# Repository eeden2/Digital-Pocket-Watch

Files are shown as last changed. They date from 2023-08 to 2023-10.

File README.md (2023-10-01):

# Digital-Pocket-Watch
This is my first invention which implements functionality for time, obviously, and a connection to a remote camera server.

# 3D-View
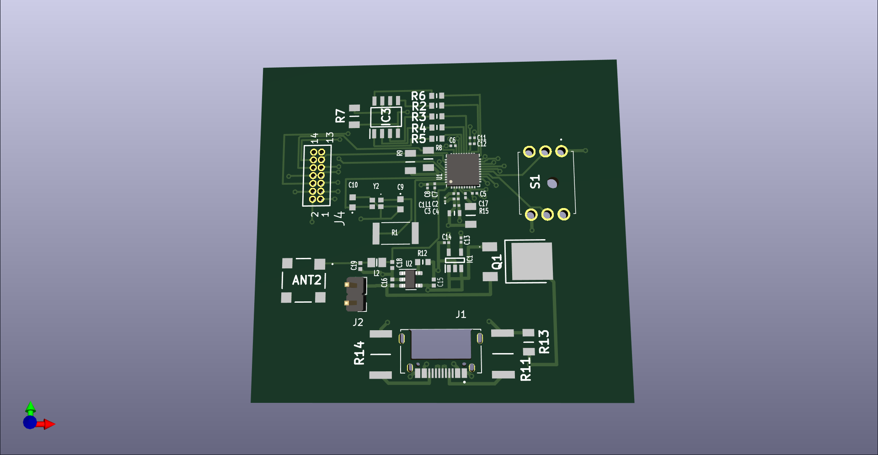
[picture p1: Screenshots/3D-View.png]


The parts are all in the mainv2/Footprints. A list here will be provided later.
- __UPDATE (10/01/2023)__
  
      The Firmware currently supports all fudamental rpotocols (I2C, WIFI, SPI, etc.)
      It also has the UI implemented for basic functionality,. Server setup for camera
      display is the only part left, but the lack of ability to manufacture it from costs
      could leave this project as is, finished.
- __The Drivers for the display are a GC9A01 SPI and a CST816S I2C Touch Interface__

# PCB
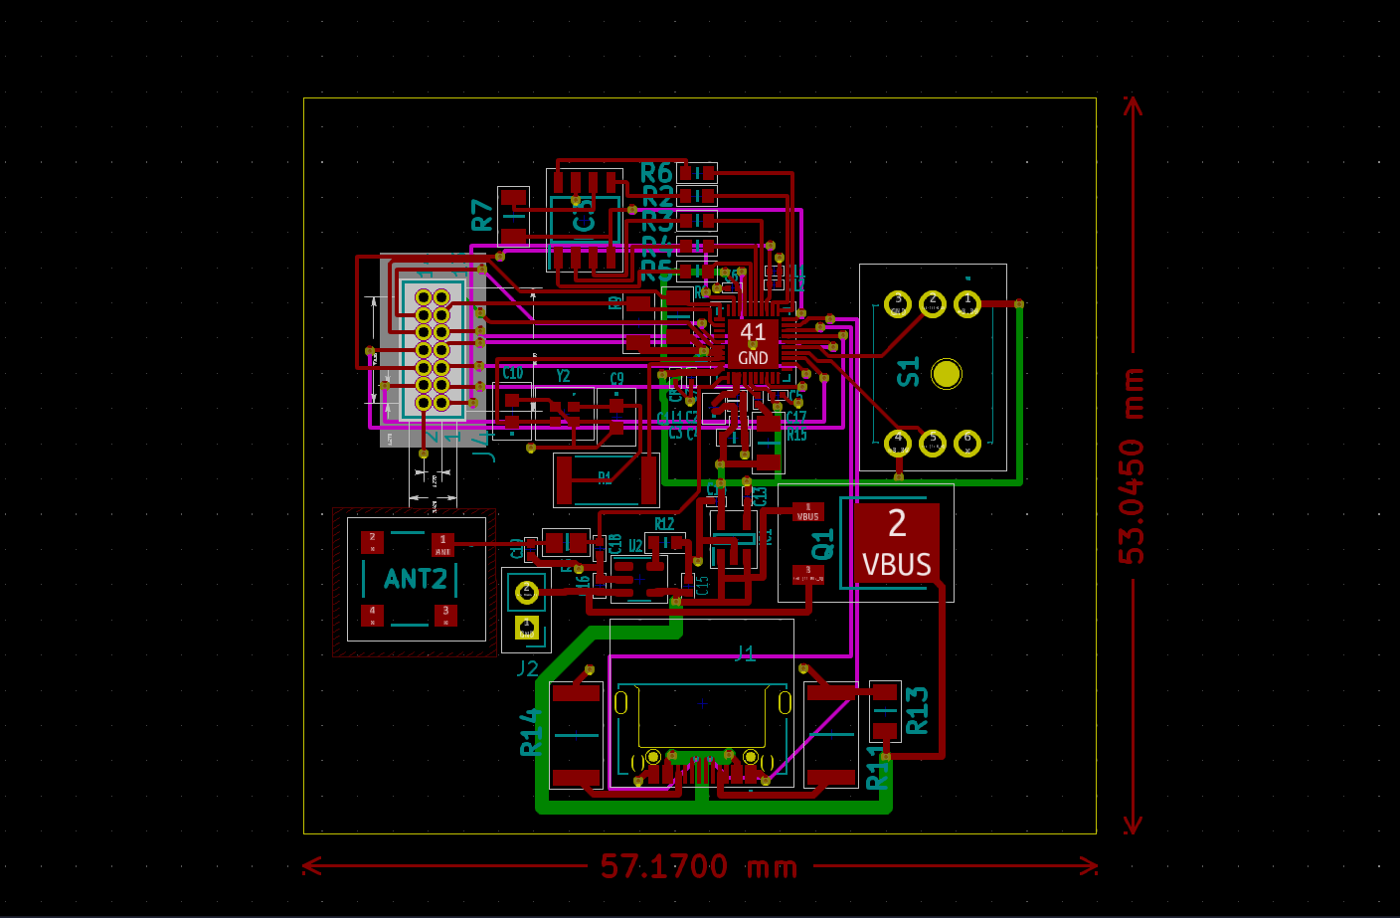
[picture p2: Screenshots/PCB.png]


# Schematic
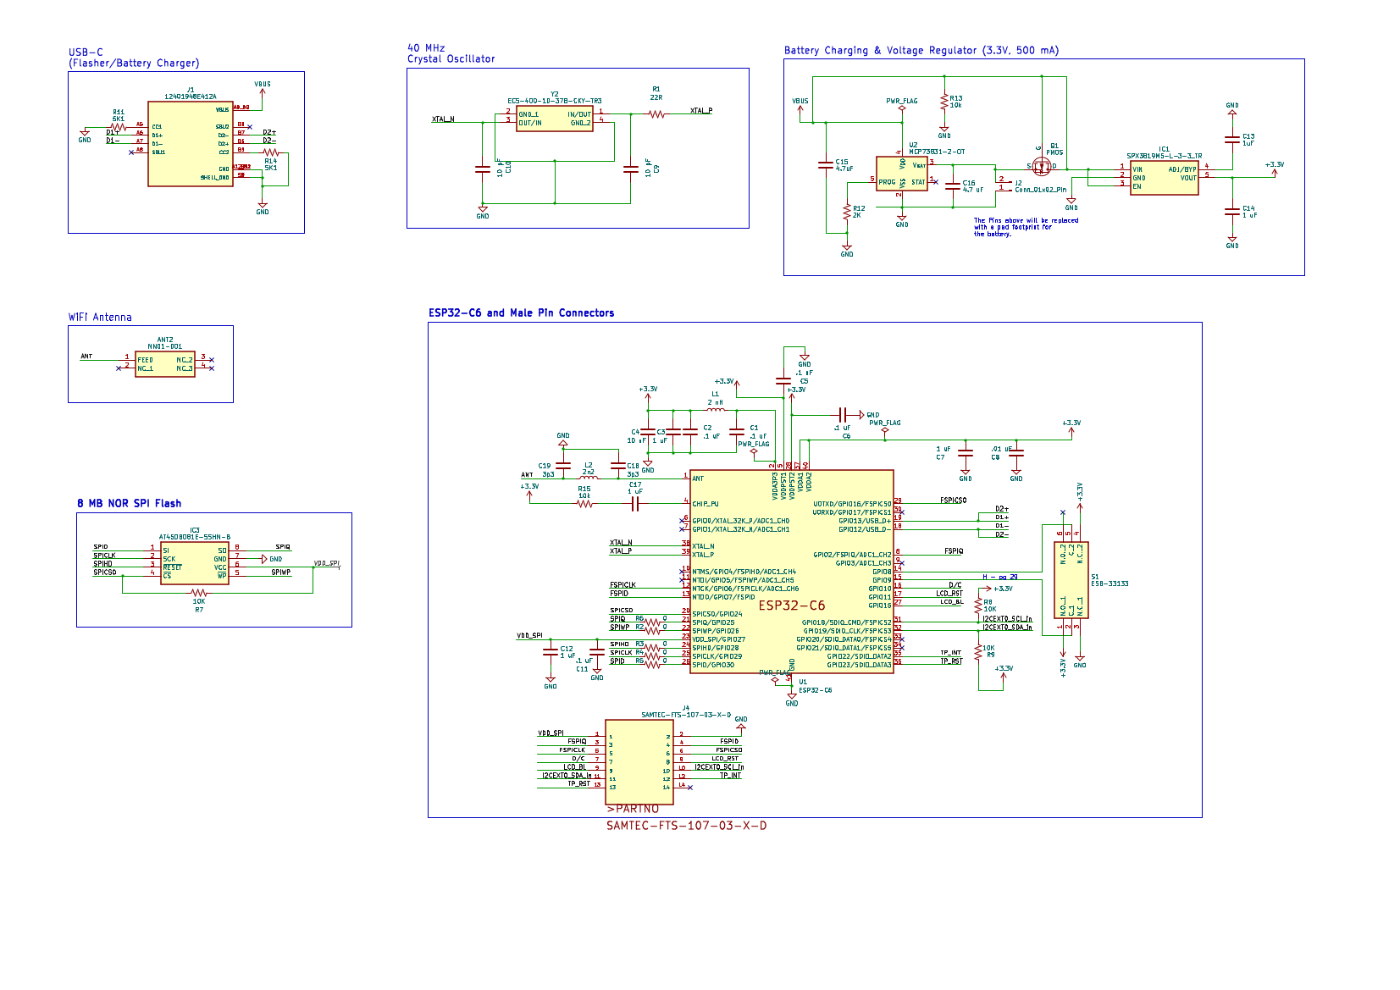
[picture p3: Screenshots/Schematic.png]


# UI Interface
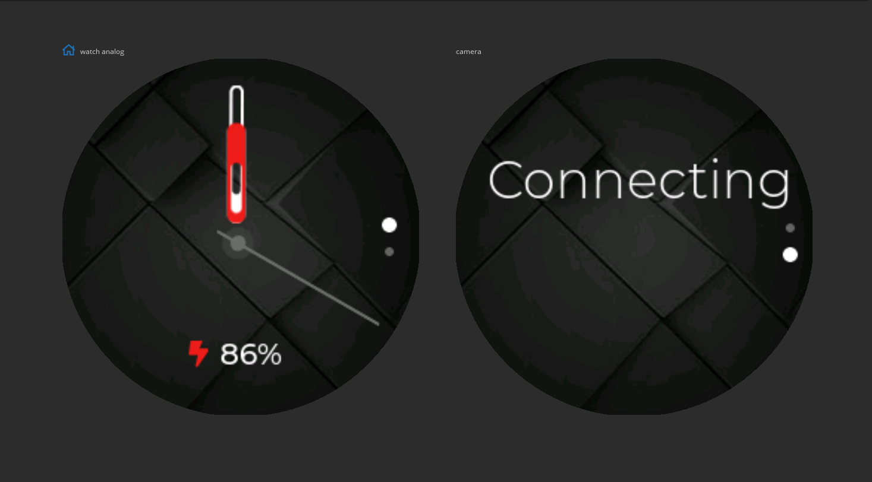
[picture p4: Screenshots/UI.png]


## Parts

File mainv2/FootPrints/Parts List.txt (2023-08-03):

Battery Charger (MCP73831T-5ACI/OT) - https://www.mouser.com/ProductDetail/Microchip-Technology/MCP73831T-5ACI-OT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
Flash (AT45DB081E-SSHN-T) - https://www.mouser.com/ProductDetail/Renesas-Dialog/AT45DB081E-SSHN-T?qs=IS%252B4QmGtzzrT9yP%2Fj4syVA%3D%3D
Battery - https://www.alibaba.com/product-detail/553535-3-7V-battery-580mah-round_60692201528.html
Button Switch (ESB-33133) - https://www.mouser.com/ProductDetail/Panasonic/ESB-33133?qs=9gtMhpKs0nEQdT3ey0aRGQ%3D%3D
Antenna (NN01-001)- https://www.mouser.com/ProductDetail/Ignion/NN01-001?qs=bAKSY%2FctAC4amJyoGr5q7A%3D%3D
Regulator (SPX3819M5-L-3-3/TR) - https://www.mouser.com/ProductDetail/MaxLinear/SPX3819M5-L-3-3-TR?qs=S%2FCBhQS5rCp1Bb7a%252BD%2FCBQ%3D%3D
Crystal (ECS-400-10-37B-CKY-TR3) - https://www.mouser.com/ProductDetail/ECS/ECS-400-10-37B-CKY-TR3?qs=TCDPyi3sCW2VtaBG%252B2IQWA%3D%3D
USB-C (12402012E212A) - https://www.mouser.com/ProductDetail/Amphenol-Commercial-Products/12402012E212A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
Display - https://www.waveshare.com/1.28inch-Touch-LCD.htm
PMOSFET - https://www.mouser.com/ProductDetail/Vishay-Semiconductors/IRFR9210PBF-BE3?qs=TCDPyi3sCW1nNZLR7LYV3w%3D%3D
13 Pin - https://www.snapeda.com/parts/TSM-113-02-T-SV-A-P-TR/Samtec/view-part/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
0 Ohm - https://www.mouser.com/ProductDetail/Ohmite/JR2512X100E?qs=sGAEpiMZZMtlubZbdhIBIM7uh3w%252BIHxmov0Yd5cNh5Y%3D
22 Ohm - https://www.snapeda.com/parts/CRGP2512F22R/TE%20Connectivity/view-part/?ref=search&t=CRGP2512F22R
10k Ohm - https://www.mouser.com/ProductDetail/Bourns/CRM2512QJW-103ELF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
2k Ohm - https://www.mouser.com/ProductDetail/TE-Connectivity-Holsworthy/35212K0FT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
5.1K OHms - https://www.mouser.com/ProductDetail/TE-Connectivity-Holsworthy/35215K1FT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
1 uF - https://www.mouser.com/ProductDetail/KEMET/C1206F105M5RACAUTO7210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
10 nF - https://www.mouser.com/ProductDetail/KYOCERA-AVX/02014D103KAT2A?qs=cnDM9bjyeUgAPyHqQrA07A%3D%3D
2.2nH - https://www.mouser.com/ProductDetail/Bourns/CE201210-2N2D?qs=8tpky8Qe03K8mDIr14buog%3D%3D
3.3 pF - https://www.mouser.com/ProductDetail/Murata-Electronics/GJM1555C1H3R3WB01D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

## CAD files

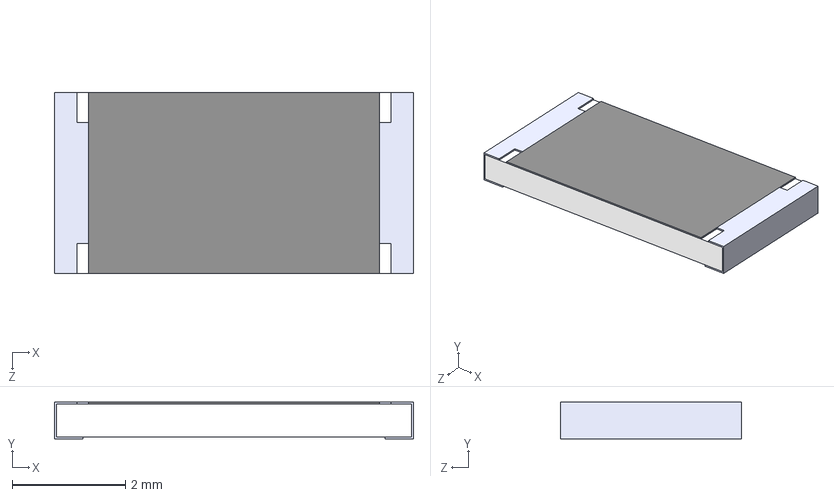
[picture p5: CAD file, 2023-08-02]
mainv2/FootPrints/CRGP2512F22R - 22Ohm/CRGP2512F22R.step
6.35 x 0.65 x 3.20 mm

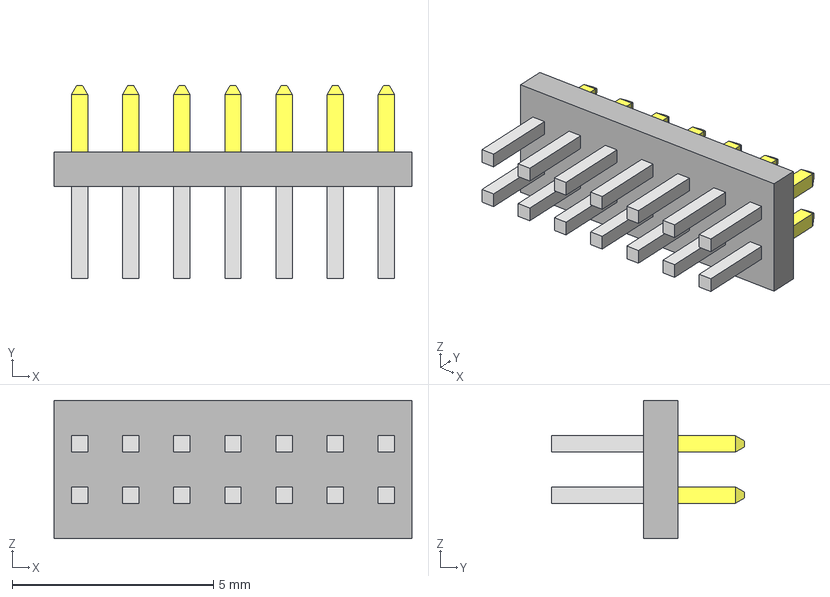
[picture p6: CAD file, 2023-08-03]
mainv2/FootPrints/FTS-107-03-L-D - 14 Pins/FTS-107-03-L-D.stp
8.89 x 4.80 x 3.43 mm
FTS-107-03-L-D_pins2
FTS-107-03-L-D_pins1
FTS-107-03-L-D_body

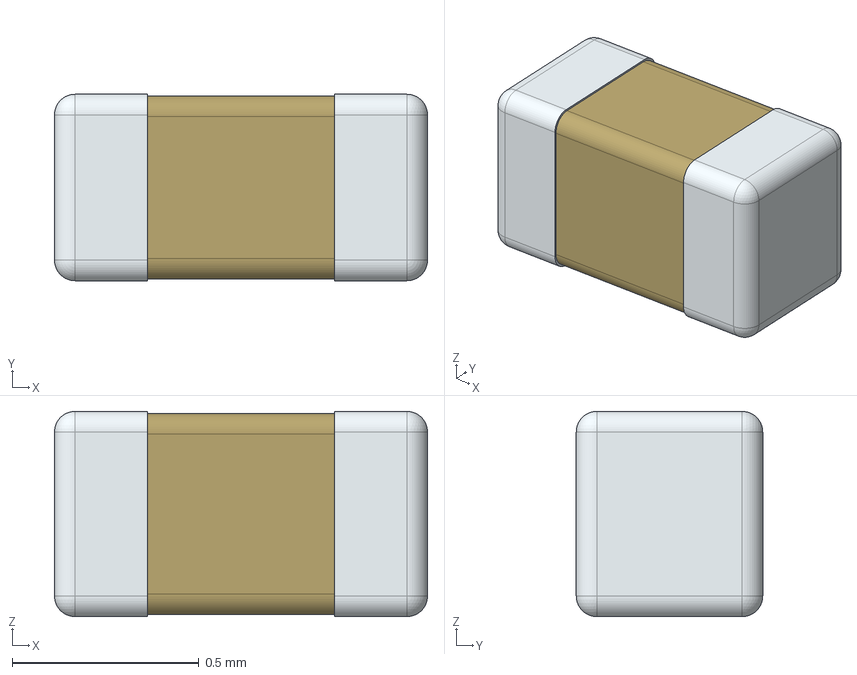
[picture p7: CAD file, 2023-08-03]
mainv2/FootPrints/LIB_GJM1555C1H3R3WB01D - 3.3pF/GJM1555C1H3R3WB01D/3D/GJM1555C1H3R3WB01D.stp
1.00 x 0.5 x 0.55 mm

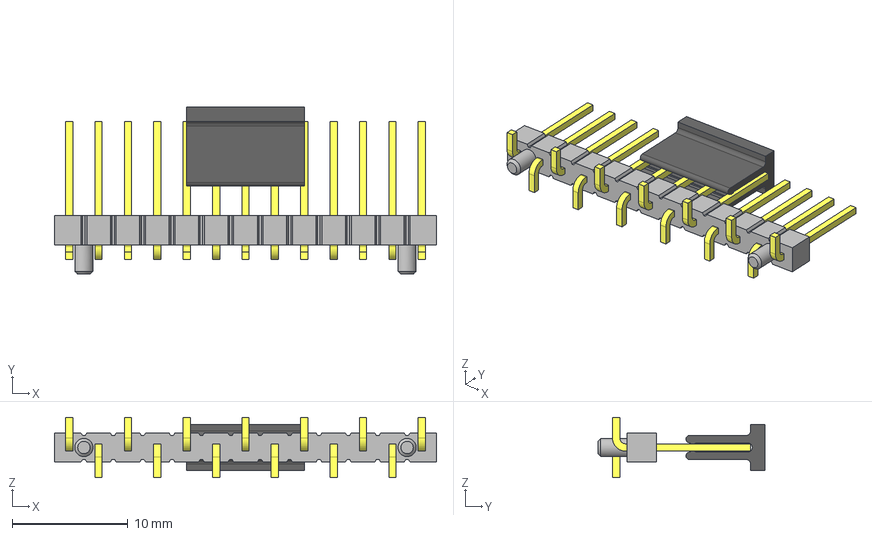
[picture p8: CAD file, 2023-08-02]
mainv2/FootPrints/TSM-113-02-T-SV-A - 13 PINS/TSM-113-02-T-SV-A.step
33.0 x 14.5 x 5.21 mm
T-1S6-08(-02-13-SV)
PPP-07-02-13--SV
TSM-113-02-SV-A_body

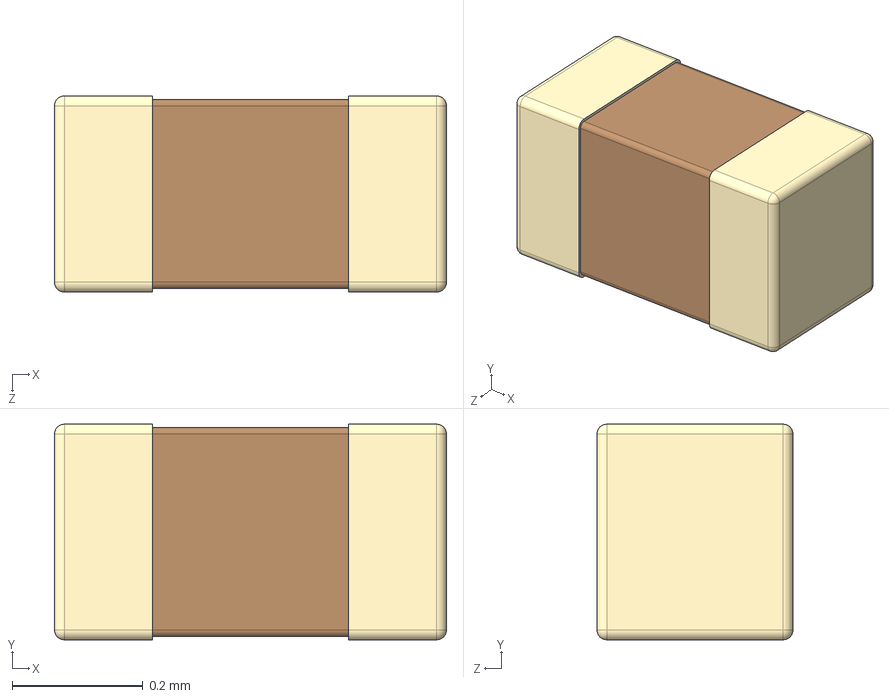
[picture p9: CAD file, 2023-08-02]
mainv2/FootPrints/02014D103KAT2A - 10 nF/02014D103KAT2A.step
0.6 x 0.33 x 0.3 mm

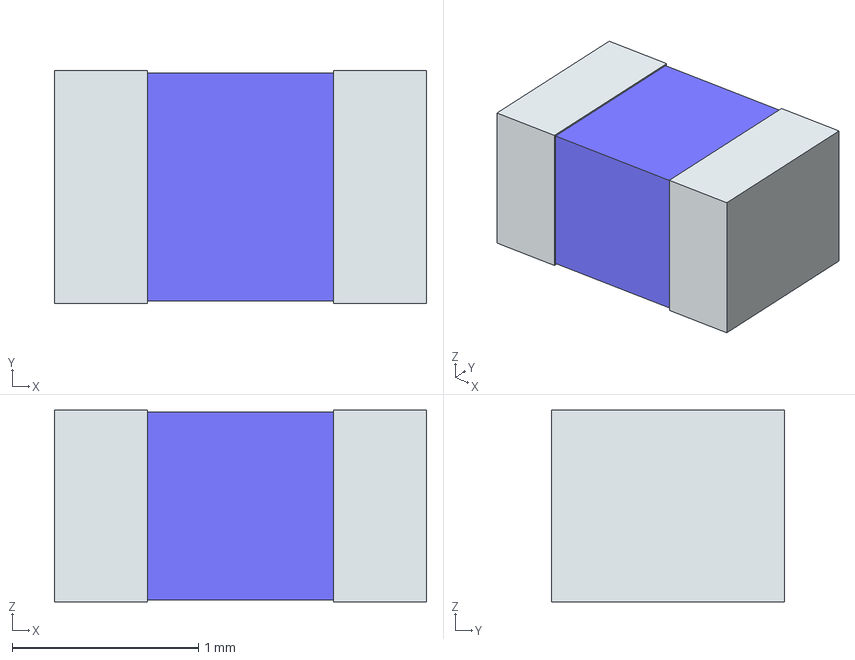
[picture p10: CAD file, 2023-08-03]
mainv2/FootPrints/LIB_CE201210-2N2D - 2.2 nH/CE201210-2N2D/3D/CE201210-2N2D.stp
2.00 x 1.25 x 1.03 mm
term1
term2

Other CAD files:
mainv2/FootPrints/LIB_CE201210-2N2D - 2.2 nH/CE201210-2N2D/Allegro/indc2012x103n.psm
mainv2/FootPrints/LIB_CE201210-2N2D - 2.2 nH/CE201210-2N2D/DEHDL/ce201210_2n2d/chips/chips.prt
mainv2/FootPrints/LIB_GJM1555C1H3R3WB01D - 3.3pF/GJM1555C1H3R3WB01D/Allegro/capc1005x55n.psm
mainv2/FootPrints/LIB_GJM1555C1H3R3WB01D - 3.3pF/GJM1555C1H3R3WB01D/DEHDL/gjm1555c1h3r3wb01d/chips/chips.prt

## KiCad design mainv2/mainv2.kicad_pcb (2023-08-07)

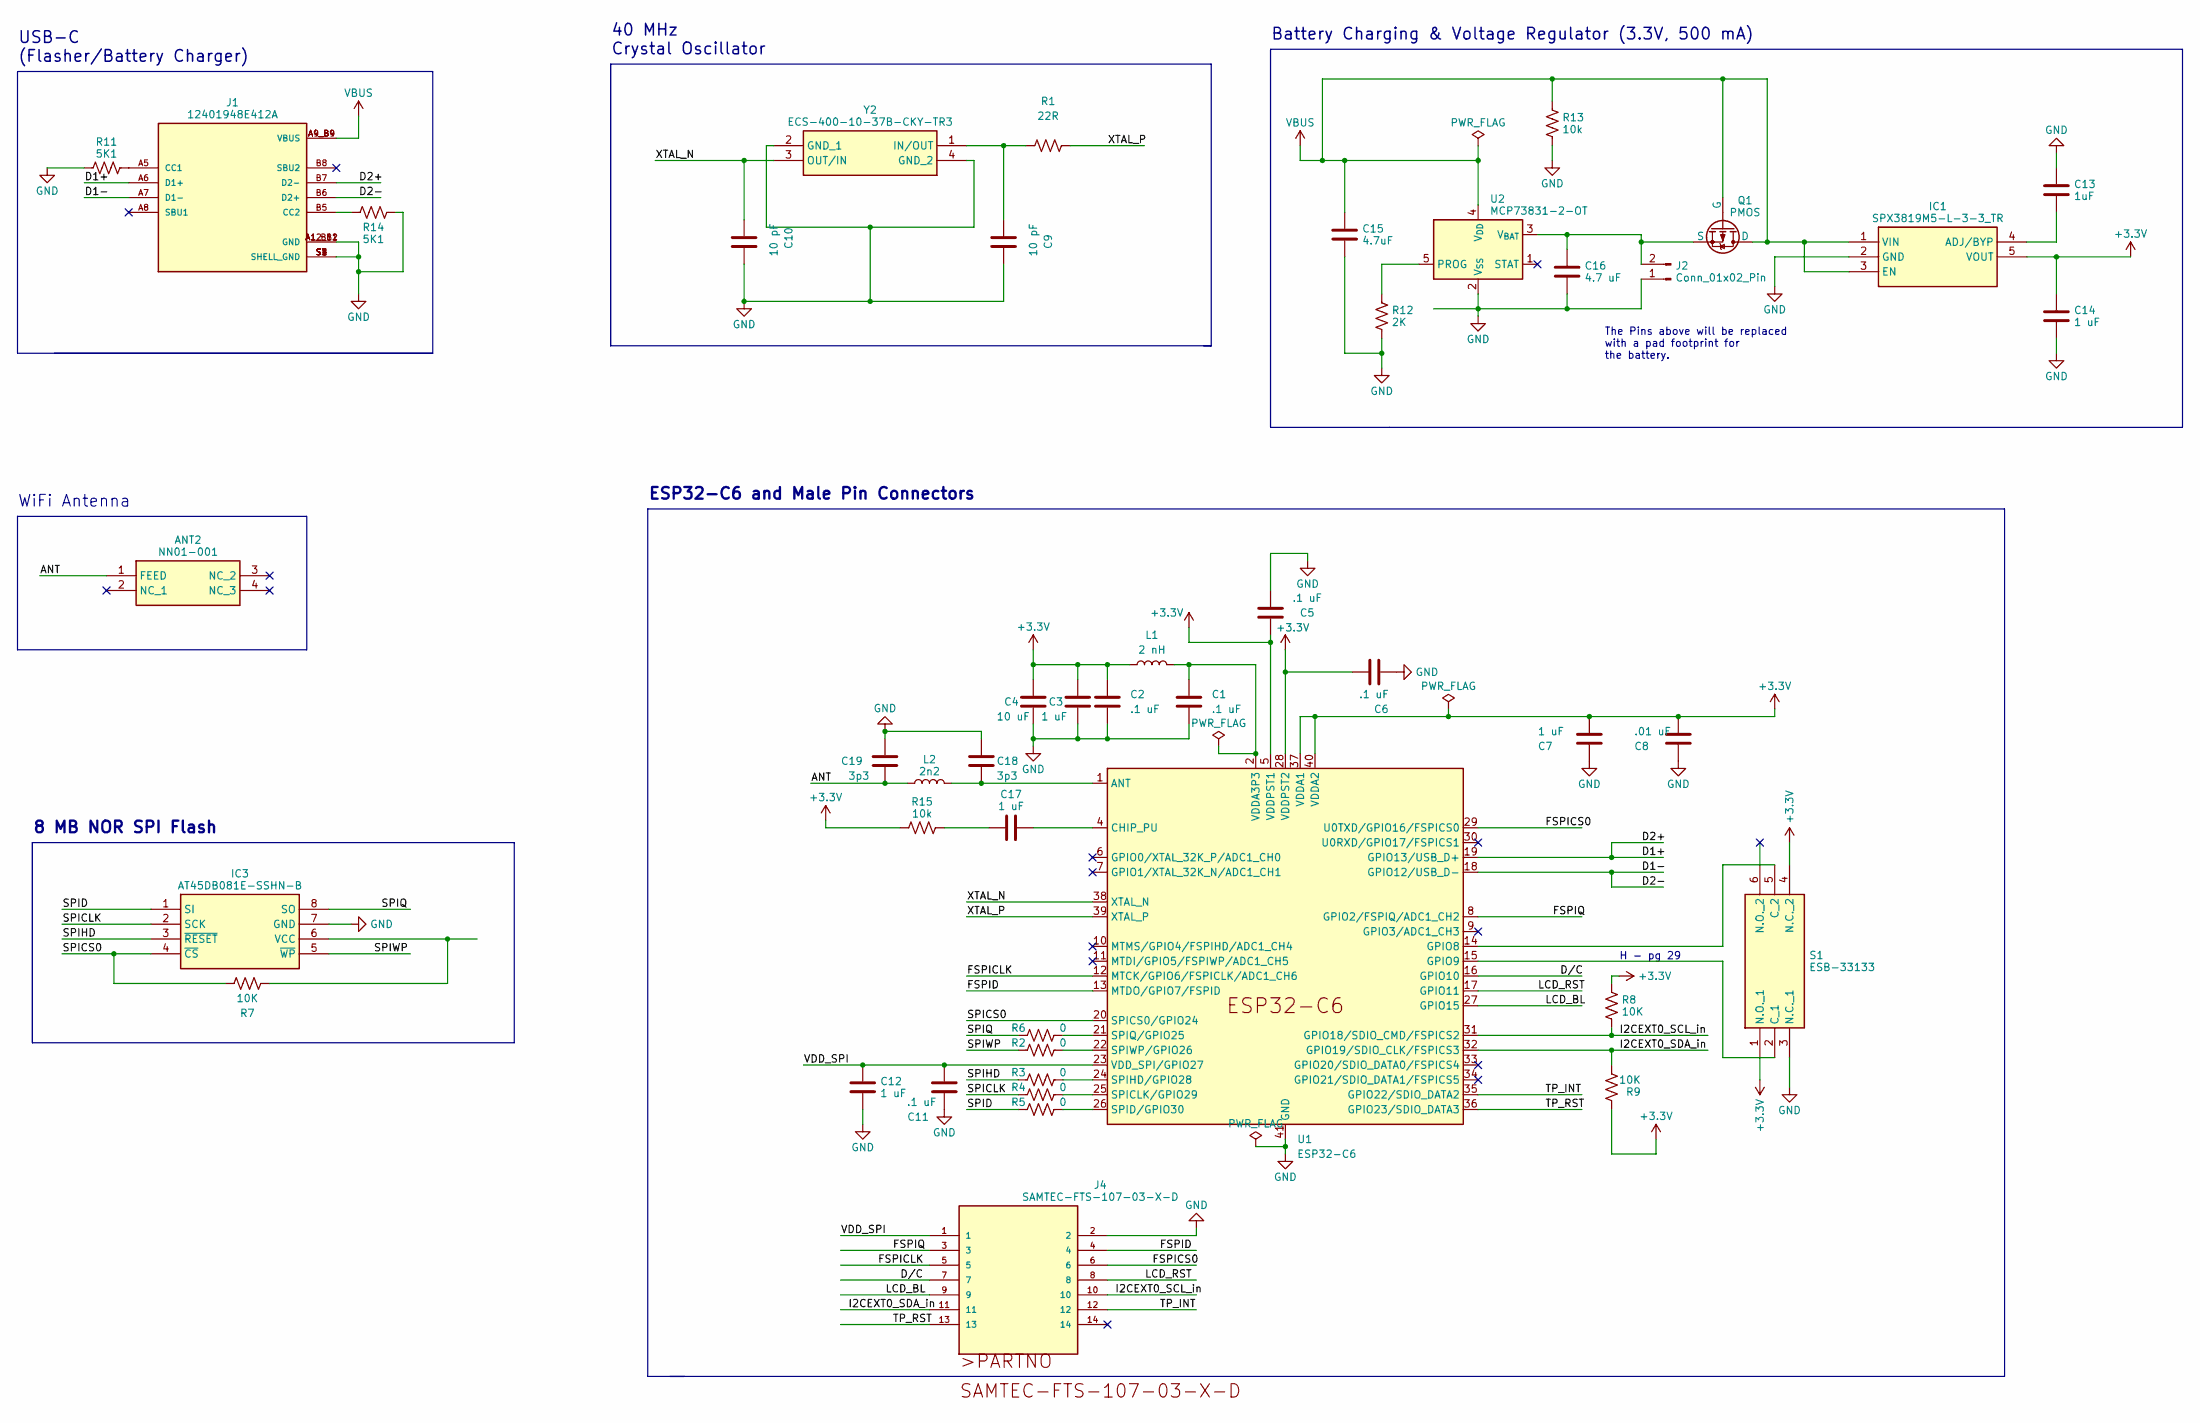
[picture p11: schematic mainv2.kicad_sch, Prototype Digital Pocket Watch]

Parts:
ANT2: NN01-001; NN01001; Manufacturer_Part_Number NN01-001
C1, C2, C5, C6, C11: .1 uF; CAPC0603X33N
C3, C7, C12, C14, C17: 1 uF; CAPC0603X35N
C4: 10 uF; CAPC1608X90N
C8: .01 uF; CAPC0603X33N
C9, C10: 10 pF; C0603
C13: 1uF; CAPC0603X35N
C15: 4.7uF; CAPC1005X55N
C16: 4.7 uF; CAPC1005X55N
C18, C19: 3p3; CAPC1005X55N
IC1: SPX3819M5-L-3-3_TR; SOT95P280X145-5N; Mouser Part Number 701-SPX3819M5-L-33TR
IC3: AT45DB081E-SSHN-B; SOIC127P600X175-8N; Mouser Part Number 988-AT45DB081ESSHN-B
J1: 12401948E412A; AMPHENOL_12401948E412A; PARTREV 3
J2: Conn_01x02_Pin; PinHeader_1x02_P2.54mm_Vertical
J4: SAMTEC-FTS-107-03-X-D
L1: 2 nH; MLG0603
L2: 2n2; INDC2012X103N
Q1: PMOS; IRFR9210PBFBE3
R1: 22R; RESC6332X65N
R2, R3, R4, R5, R6: 0; RESC1608X55N
R7, R8, R9: 10K; RESC3116X65N
R11, R14: 5K1; RESC6432X65N
R12: 2K; RESC1608X55N
R13, R15: 10k; RESC3116X65N
S1: ESB-33133; ESB33133; Mouser Part Number 667-ESB-33133
U1: ESP32-C6; QFN-40-1EP_5x5mm_P0.4mm_EP3.6x3.6mm
U2: MCP73831-2-OT; SOT-23-5
Y2: ECS-400-10-37B-CKY-TR3; ECS4001037BCKYTR3; Mouser Part Number 520-EC4001037BCKYTR3

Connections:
+3.3V: C2.1, C3.1, C4.1, C5.1, C6.1, C7.1, C8.1, C14.1, IC1.5 (VOUT), L1.1, R8.1, R9.1, R15.1, S1.1 (N.O._1), S1.4 (N.C._2), U1.5 (VDDPST1), U1.28 (VDDPST2), U1.37 (VDDA1), U1.40 (VDDA2)
/ANT: ANT2.1 (FEED), C19.2, L2.1
/D1+: J1.A6 (D1+), J1.B7 (D2-), U1.19 (GPIO13/USB_D+)
/D1-: J1.A7 (D1-), J1.B6 (D2+), U1.18 (GPIO12/USB_D-)
/D/C: J4.7, U1.16 (GPIO10)
/FSPICLK: J4.5, U1.12 (MTCK/GPIO6/FSPICLK/ADC1_CH6)
/FSPICS0: J4.6, U1.29 (U0TXD/GPIO16/FSPICS0)
/FSPID: J4.4, U1.13 (MTDO/GPIO7/FSPID)
/FSPIQ: J4.3, U1.8 (GPIO2/FSPIQ/ADC1_CH2)
/I2CEXT0_SCL_in: J4.10, R8.2, U1.31 (GPIO18/SDIO_CMD/FSPICS2)
/I2CEXT0_SDA_in: J4.11, R9.2, U1.32 (GPIO19/SDIO_CLK/FSPICS3)
/LCD_BL: J4.9, U1.27 (GPIO15)
/LCD_RST: J4.8, U1.17 (GPIO11)
/SPICLK: IC3.2 (SCK), R4.1
/SPICS0: IC3.4 (~CS), R7.1, U1.20 (SPICS0/GPIO24)
/SPID: IC3.1 (SI), R5.1
/SPIHD: IC3.3 (~RESET), R3.1
/SPIQ: IC3.8 (SO), R6.1
/SPIWP: IC3.5 (~WP), R2.1
/TP_INT: J4.12, U1.35 (GPIO22/SDIO_DATA2)
/TP_RST: J4.13, U1.36 (GPIO23/SDIO_DATA3)
/VDD_SPI: C11.2, C12.2, J4.1, U1.23 (VDD_SPI/GPIO27)
/XTAL_N: C10.1, U1.38 (XTAL_N), Y2.3 (OUT/IN)
/XTAL_P: R1.2, U1.39 (XTAL_P)
GND: C1.2, C2.2, C3.2, C4.2, C5.2, C6.2, C7.2, C8.2, C9.2, C10.2, C11.1, C12.1, C13.1, C14.2, C15.2, C16.2, C18.1, C19.1, IC1.2 (GND), IC3.7 (GND), J1.A1_B12 (GND), J1.A12_B1 (GND), J1.S1 (SHELL_GND), J1.S2 (SHELL_GND), J1.S3 (SHELL_GND), J1.S4 (SHELL_GND), J2.1, J4.2, R11.1, R12.2, R13.2, R14.2, S1.3 (N.C._1), U1.41 (GND), U2.2 (V_{SS}), Y2.2 (GND_1), Y2.4 (GND_2)
unnamed: C1.1, L1.2, U1.2 (VDDA3P3), U1.3 (VDDA3P3)
unnamed: C17.1, R15.2
unnamed: C13.2, IC1.4 (ADJ/BYP)
unnamed: IC3.6 (VCC), R7.2
unnamed: J1.A5 (CC1), R11.2
unnamed: J1.B5 (CC2), R14.1
unnamed: C16.1, J2.2, Q1.3 (S), U2.3 (V_{BAT})
unnamed: S1.2 (C_1), U1.15 (GPIO9)
unnamed: S1.5 (C_2), U1.14 (GPIO8)
unnamed: C18.2, L2.2, U1.1 (ANT)
unnamed: C17.2, U1.4 (CHIP_PU)
unnamed: R4.2, U1.25 (SPICLK/GPIO29)
unnamed: R5.2, U1.26 (SPID/GPIO30)
unnamed: R3.2, U1.24 (SPIHD/GPIO28)
unnamed: R6.2, U1.21 (SPIQ/GPIO25)
unnamed: R2.2, U1.22 (SPIWP/GPIO26)
unnamed: R12.1, U2.5 (PROG)
unnamed: C9.1, R1.1, Y2.1 (IN/OUT)
VBUS: C15.1, IC1.1 (VIN), IC1.3 (EN), J1.A4_B9 (VBUS), J1.A9_B4 (VBUS), Q1.1 (D), Q1.2 (G), R13.1, U2.4 (V_{DD})

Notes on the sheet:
H - pg 29
ESP32-C6 and Male Pin Connectors
The Pins above will be replaced with a pad footprint for the battery.
USB-C (Flasher/Battery Charger)
Battery Charging & Voltage Regulator (3.3V, 500 mA)
WiFi Antenna
8 MB NOR SPI Flash
40 MHz Crystal Oscillator

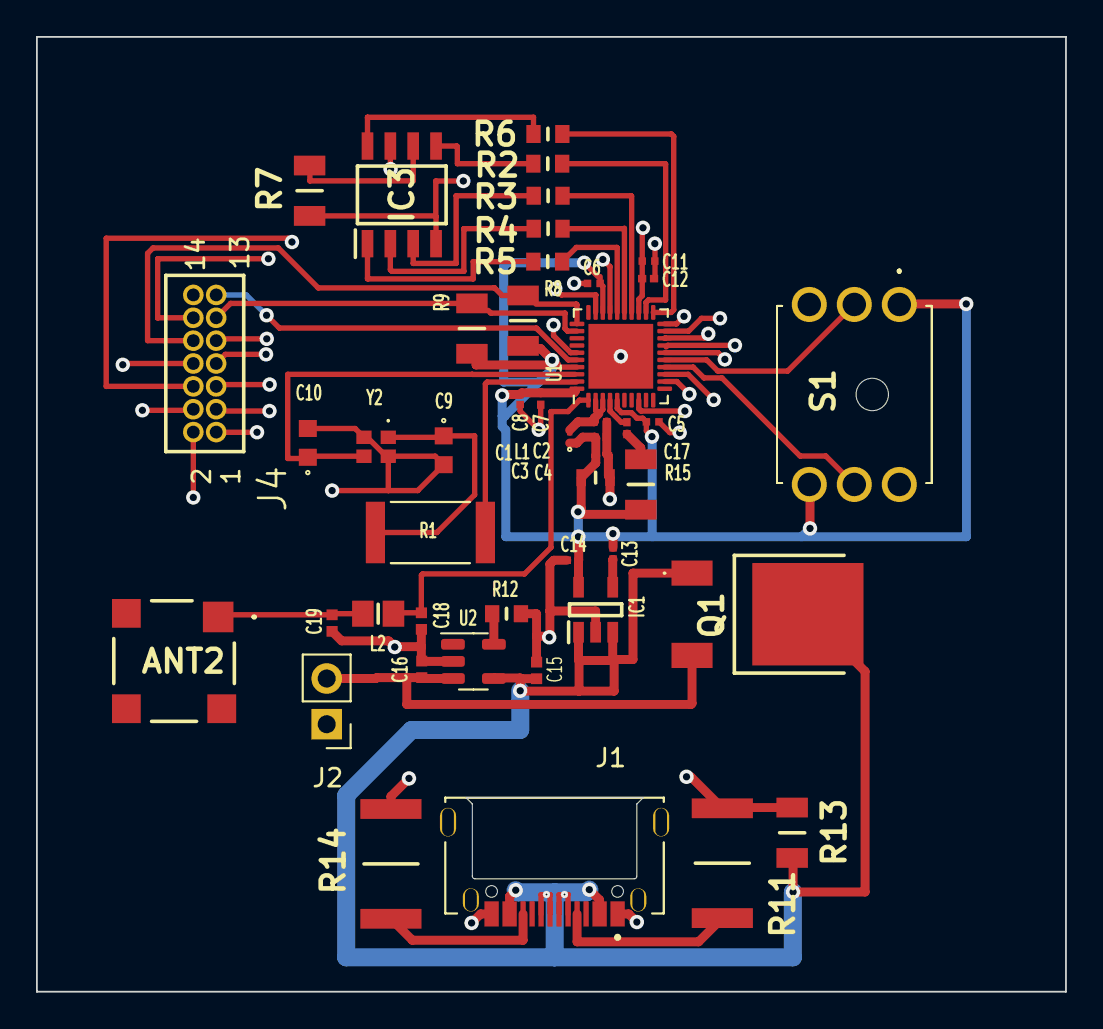
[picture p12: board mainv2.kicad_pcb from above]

Board: 4 copper layers, 57.2 x 53.0 mm, 46 parts (0 on the bottom side), 44 nets.

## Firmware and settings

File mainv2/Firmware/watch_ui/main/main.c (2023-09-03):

#include <stdio.h>
#include <lvgl.h>
#include <inttypes.h>
#include "sdkconfig.h"
#include "freertos/FreeRTOS.h"
#include "freertos/task.h"
#include <esp_timer.h>
#include "driver/gpio.h"
#include "esp_log.h"
#include "esp_err.h"
#include "hal/lcd_types.h"
#include "gpio.h"
#include "esp_lcd_panel_io.h"
#include "esp_lcd_gc9a01.h"
#include "esp_lcd_panel_vendor.h"
#include "esp_lcd_panel_ops.h"
#include "protocols/I2C.c"
#include "protocols/SPI.c"
#include "protocols/WIFI.c"
#include "signal.h"
#include "spi_master.h"
#include "ui/ui.c"
#include "protocols/timer_replacement.h" // This file was made due to the esp_timer.h not allowing use of its defined functions.

#define FSPIQ_IN_IDX                  64
#define FSPIQ_OUT_IDX                 64
#define FSPID_IN_IDX                  65
#define FSPID_OUT_IDX                 65
#define FSPICS0_IN_IDX                68
#define FSPICS0_OUT_IDX               68
#define LCD_HOST SPI2_HOST

#define portTICK_PERIOD_MS      1                       //This was defined manually because my IDE was not reading it from "sdkconfig.h"

#define LVGL_TICK_PERIOD_MS     2

//Antenna
#define ANT                     1

//USB Diffs
#define D_PLUS                  GPIO_NUM_13
#define D_NEG                   GPIO_NUM_12

//Flash Switch for when Chip is in download mode or regular SPI mode
#define FIRST_SWITCH            GPIO_NUM_8
#define SECOND_SWITCH           GPIO_NUM_9


extern void lvgl_demo_ui(lv_disp_t *disp);


static bool notify_lvgl_flush_ready(esp_lcd_panel_io_handle_t panel_io, esp_lcd_panel_io_event_data_t *edata, void *user_ctx)
{
    lv_disp_drv_t *disp_driver = (lv_disp_drv_t *)user_ctx;
    lv_disp_flush_ready(disp_driver);
    return false;
}

static void lvgl_flush_cb(lv_disp_drv_t *drv, const lv_area_t *area, lv_color_t *color_map)
{
    esp_lcd_panel_handle_t panel_handle = (esp_lcd_panel_handle_t) drv->user_data;
    int offsetx1 = area->x1;
    int offsetx2 = area->x2;
    int offsety1 = area->y1;
    int offsety2 = area->y2;
    // copy a buffer's content to a specific area of the display
    esp_lcd_panel_draw_bitmap(panel_handle, offsetx1, offsety1, offsetx2 + 1, offsety2 + 1, color_map);
}

/* Rotate display and touch, when rotated screen in LVGL. Called when driver parameters are updated. */
static void lvgl_port_update_callback(lv_disp_drv_t *drv)
{
    esp_lcd_panel_handle_t panel_handle = (esp_lcd_panel_handle_t) drv->user_data;

    switch (drv->rotated) {
    case LV_DISP_ROT_NONE:
        // Rotate LCD display
        esp_lcd_panel_swap_xy(panel_handle, false);
        esp_lcd_panel_mirror(panel_handle, true, false);

        break;
    case LV_DISP_ROT_90:
        // Rotate LCD display
        esp_lcd_panel_swap_xy(panel_handle, true);
        esp_lcd_panel_mirror(panel_handle, true, true);

        break;
    case LV_DISP_ROT_180:
        // Rotate LCD display
        esp_lcd_panel_swap_xy(panel_handle, false);
        esp_lcd_panel_mirror(panel_handle, false, true);

        break;
    case LV_DISP_ROT_270:
        // Rotate LCD display
        esp_lcd_panel_swap_xy(panel_handle, true);
        esp_lcd_panel_mirror(panel_handle, false, false);

        break;
    }
}

static void increase_lvgl_tick(void *arg)
{
    /* Tell LVGL how many milliseconds has elapsed */
    lv_tick_inc(LVGL_TICK_PERIOD_MS);
}



void app_main(void)
{
    static lv_disp_draw_buf_t disp_buf;
    static lv_disp_drv_t disp_drv;

    ESP_LOGI(TAG, "Turn off LCD backlight.");
    gpio_config_t bk_gpio_config = 
    {
        .mode = GPIO_MODE_OUTPUT,
        .pin_bit_mask = 1ULL << LCD_BL
    };
 
    //Setting GPIO pins to alternate fucntions via the GPIO Matrix
    gpio_reset_pin(GPIO_NUM_6);
    gpio_iomux_in(GPIO_NUM_6, FSPID_IN_IDX);
    gpio_reset_pin(GPIO_NUM_7);
    gpio_iomux_in(GPIO_NUM_7, FSPID_OUT_IDX);
    gpio_reset_pin(GPIO_NUM_2);
    gpio_iomux_in(GPIO_NUM_2, FSPIQ_IN_IDX);
    gpio_reset_pin(GPIO_NUM_21);
    gpio_iomux_in(GPIO_NUM_21, FSPICS0_OUT_IDX);
    
    //Now, the FSPI Pins will be configured to then be implemented in the LCD API From ESP-IDF
    spi_bus_config_t buscfg = 
    {
        .sclk_io_num = GPIO_NUM_6,
        .mosi_io_num = GPIO_NUM_7,
        .miso_io_num = GPIO_NUM_2,
        .quadwp_io_num = -1,
        .quadhd_io_num = -1,
        .max_transfer_sz = LCD_H_RES * 80 * sizeof(uint16_t),
    };
    ESP_ERROR_CHECK(spi_bus_initialize(FSPIQ, &buscfg, SPI_DMA_CH_AUTO));
    
    //After initializing the SPI Bus config, we now can config the SPI interface with the LCD API
    esp_lcd_panel_io_handle_t panel_IO = NULL;
    esp_lcd_panel_io_spi_config_t config_IO = 
    {
        .dc_gpio_num = D_C,
        .cs_gpio_num = FSPICS0,
        .pclk_hz = LCD_PIXEL_CLOCK_HZ,
        .lcd_cmd_bits = LCD_CMD_BITS,
        .lcd_param_bits = LCD_PARAM_BITS,
        .spi_mode = 0,
        .trans_queue_depth = 10,
        .on_color_trans_done = notify_lvgl_flush_ready,
        .user_ctx = &disp_drv,
    };

    //Checking for Errors before adding LCD to SPI Bus
    ESP_ERROR_CHECK(esp_lcd_new_panel_io_spi((esp_lcd_spi_bus_handle_t)LCD_HOST,&config_IO,&panel_IO));

    esp_lcd_panel_handle_t handle_my_panel = NULL;
    esp_lcd_panel_dev_config_t config_my_panel = 
    {
        .reset_gpio_num = LCD_RST,
        .rgb_endian = LCD_RGB_ENDIAN_BGR,
        .bits_per_pixel = 16,
    };

    //Install that which handles my panel :)
    ESP_LOGI(TAG, "Installing the Panel Handler.");
    ESP_ERROR_CHECK(esp_lcd_new_panel_gc9a01(panel_IO, &config_my_panel,&handle_my_panel));
    
    //Initialize the Panel
    ESP_ERROR_CHECK(esp_lcd_panel_reset(handle_my_panel));
    ESP_ERROR_CHECK(esp_lcd_panel_init(handle_my_panel));

    //The colors must be inverted due to the config following a BGR Endian
    ESP_ERROR_CHECK(esp_lcd_panel_invert_color(handle_my_panel, true));

    ESP_ERROR_CHECK(esp_lcd_panel_disp_on_off(handle_my_panel, true));

    /*need to initialize the i2c interface for the
    touch panel*/

    ESP_ERROR_CHECK(i2c_master_init());
    ESP_LOGI(TAG,"Initialized I2C.");


    ESP_LOGI(TAG, "Initialize LVGL Library");
    lv_init();

    lv_color_t *buf1 = heap_caps_malloc(LCD_H_RES* 20 * sizeof(lv_color_t), MALLOC_CAP_INTERNAL);
    assert(buf1);
    lv_color_t *buf2 = heap_caps_malloc(LCD_H_RES * 20 * sizeof(lv_color_t), MALLOC_CAP_INTERNAL);
    assert(buf2);

    //start LVGL Drawing buffers.
    lv_disp_set_draw_buffers(&disp_buf, buf1, buf2, LCD_H_RES*20);

    ESP_LOGI(TAG, "Register Display Driver to LVGL.");
    //lv_disp_set_driver_data(&disp_drv, NULL);
    disp_drv.hor_res = LCD_H_RES;
    disp_drv.ver_res = LCD_V_RES;
    disp_drv.flush_cb = lvgl_flush_cb;
    disp_drv.drv_update_cb = lvgl_port_update_callback;
    disp_drv.draw_buf = &disp_buf;
    disp_drv.user_data = handle_my_panel;
    
    
    //This is the meat of what starts the squarline interface UI.
    lv_disp_t *disp = lv_disp_set_driver_data(&disp_drv,NULL);
    lv_theme_t * theme = lv_theme_basic_init(disp);
    lv_disp_set_theme(disp, theme);
    ui_watch_analog_screen_init();
    ui_camera_screen_init();
    ui____initial_actions0 = lv_obj_create(NULL);
    lv_obj_add_event_cb(ui____initial_actions0,ui_event____initial_actions0,LV_EVENT_ALL, NULL);

    lv_disp_load_scr(ui____initial_actions0);
    lv_disp_load_scr(ui_watch_analog);
    //This is the end of the meat for starting the UI.


    ESP_LOGI(TAG, "Install LVGL tick timer");
    // Tick interface for LVGL (using esp_timer to generate 2ms periodic event)
    const esp_timer_create_args_t lvgl_tick_timer_args = {
        .callback = &increase_lvgl_tick,
        .name = "lvgl_tick"
    };
    esp_timer_handle_t lvgl_tick_timer = NULL;
    ESP_ERROR_CHECK(esp_timer_create(&lvgl_tick_timer_args, &lvgl_tick_timer));
    ESP_ERROR_CHECK(esp_timer_start_periodic(lvgl_tick_timer, LVGL_TICK_PERIOD_MS * 1000));

    ESP_LOGI(TAG, "Start example GUI");
    lvgl_demo_ui(disp);
    


    printf("Hello world!\n");
    
    

    while (1) {
        // raise the task priority of LVGL and/or reduce the handler period can improve the performance
        vTaskDelay(pdMS_TO_TICKS(10));
        // The task running lv_timer_handler should have lower priority than that running `lv_tick_inc`
        lv_timer_handler();
    }
}

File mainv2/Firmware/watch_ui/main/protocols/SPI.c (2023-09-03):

#include <stdio.h>
#include <inttypes.h>
#include "sdkconfig.h"
#include "freertos/FreeRTOS.h"
#include "freertos/task.h"
#include "esp_timer.h"
#include "esp_chip_info.h"
#include "esp_log.h"
#include "esp_err.h"


// 4MB Flash SPI
#define SPICLK                  25
#define SPID                    26
#define SPIQ                    21
#define SPICS0                  20

// LCD SPI Pins
#define FSPI_CLK                GPIO_NUM_6
#define FSPID                   GPIO_NUM_7
#define FSPIQ                   GPIO_NUM_2
#define FSPICS0                 GPIO_NUM_16
#define LCD_RST                 GPIO_NUM_15
#define LCD_BL                  GPIO_NUM_11
#define D_C                     GPIO_NUM_10

//LCD Properties
#define LCD_PIXEL_CLOCK_HZ      (20 * 1000 * 1000)
#define LCD_BK_LIGHT_ON_LEVEL   1
#define LCD_BK_LIGHT_OFF_LEVEL  !EXAMPLE_LCD_BK_LIGHT_ON_LEVEL

//Pixel Resolutions
#define LCD_H_RES               240
#define LCD_V_RES               240

// Bit number used to represent command and parameter
#define LCD_CMD_BITS            8
#define LCD_PARAM_BITS          8

#define portTICK_PERIOD_MS      1                       //This was defined manually because my IDE was not reading it from "sdkconfig.h"

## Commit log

2023-08-03 Added a setup for the LCD SPI Bus.
2023-08-03 Tidying up
    [CAPC1005X55N.PcbLib, CE201210-2N2D.SchLib, CE201210-2N2D.stp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]
2023-08-06 updated layout 8/06/2023
    [mainv2-B_Cu.gbr, mainv2-B_Mask.gbr, mainv2-B_Paste.gbr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]
2023-08-06 Redesigned board and setup LCD Display Driver.
2023-08-07 Added Current Screenshots for a Visual Flair.
    [mainv2.kicad_pcb, mainv2.kicad_sch]
2023-08-07 Board Update
    [mainv2-B_Cu.gbr, mainv2-B_Mask.gbr, mainv2-B_Paste.gbr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]
2023-08-27 Restructed project with no include errors
    [I2C.c, SPI.c, main.c]
2023-09-03 Setup the WIFI driver and implemented watch UI.

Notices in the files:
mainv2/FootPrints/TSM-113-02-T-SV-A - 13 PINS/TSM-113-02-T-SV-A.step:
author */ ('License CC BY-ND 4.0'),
